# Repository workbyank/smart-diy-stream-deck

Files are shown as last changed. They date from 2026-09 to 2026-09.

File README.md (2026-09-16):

# Smart DIY Stream Deck

A custom USB HID macro controller with 9 programmable keys, OLED system monitoring, rotary volume control, and a 3D-printed enclosure.

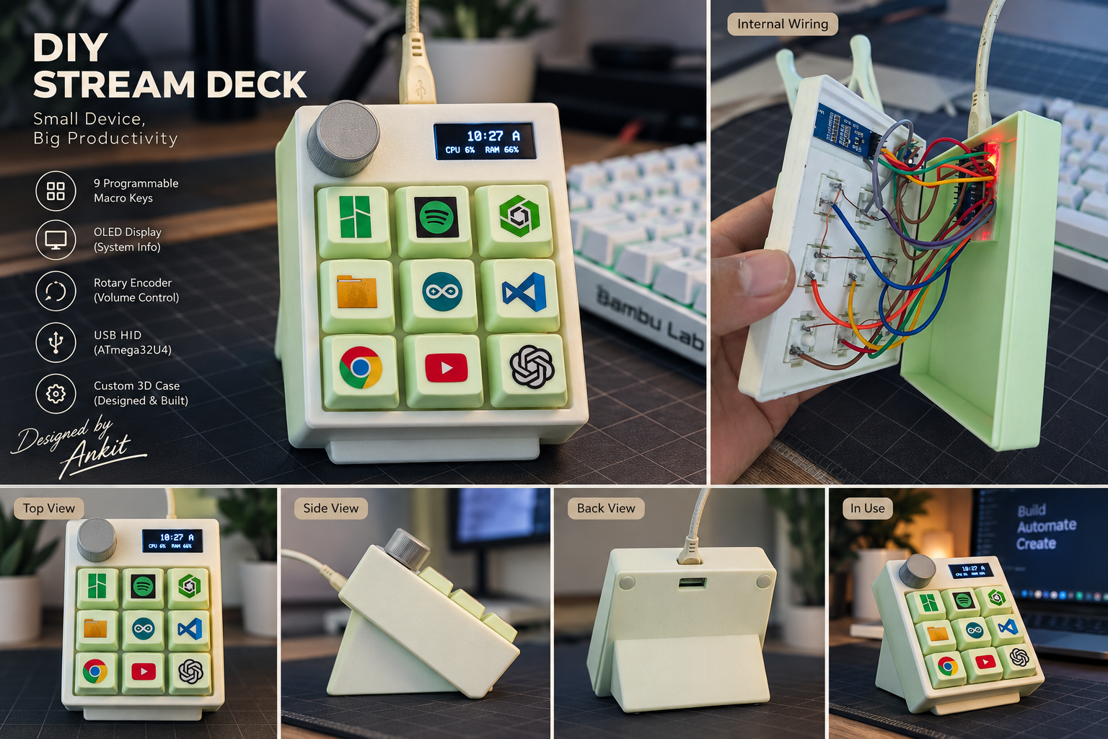
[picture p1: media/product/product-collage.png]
Smart DIY Stream Deck


`Arduino` `ATmega32U4` `USB HID` `AutoHotkey` `Onshape` `3D Printing`

---

## Overview

Smart DIY Stream Deck is a **9-key USB macro pad** built around an ATmega32U4 Pro Micro. It launches applications and websites, controls Windows system volume through a rotary encoder, and uses its OLED screen to show live feedback — including, once idle, the PC's current time, CPU load, and RAM usage.

The project spans firmware, desktop automation, serial communication, and mechanical design:

- Embedded systems (Arduino/AVR)
- USB HID (keyboard + consumer control)
- OLED / I2C display programming
- Rotary encoder input handling
- Desktop automation (AutoHotkey)
- Serial communication (USB-CDC)
- 3D CAD and 3D printing

This repository documents the project as it was actually built — implemented features and known limitations are called out explicitly throughout.

---

## Key Features

- 9 programmable macro keys
- Direct USB HID keyboard shortcuts (no clipboard tricks, no Win+R)
- Per-key application/website launching via a Windows-side launcher
- OLED status interface with a per-app icon and drop-in animation
- Idle screen showing PC time, CPU usage, and RAM usage
- Rotary encoder volume control (clockwise/counter-clockwise)
- Encoder push-button mute/unmute
- Custom 3D-printed enclosure
- AutoHotkey-based desktop automation (application launching + PC telemetry)
- Native USB on the ATmega32U4 (HID and Serial share one USB connection)

---

## Demo / Preview

The collage above shows the assembled macro pad from multiple angles (top, side, back, in active use) and the internal wiring, all from a single project photo set.

---

## Hardware

| Component | Qty | Purpose |
|---|---|---|
| ATmega32U4 Pro Micro (5V / 16MHz) | 1 | Main controller, native USB HID |
| 0.91" 128×32 I2C OLED | 1 | Status / idle display |
| Mechanical push switches | 9 | Macro key inputs |
| Rotary encoder with push switch | 1 | Volume control + mute |
| USB cable | 1 | Power + USB HID/Serial |
| Custom 3D-printed enclosure | 1 | Housing |
| Connecting wires | as required | Wiring |

Full details: [`hardware/bill-of-materials.md`](hardware/bill-of-materials.md)

---

## Key Mapping

| Key | Application | Action |
|---|---|---|
| K1 | ChatGPT | Launch (website) |
| K2 | Bambu Studio | Launch (desktop app) |
| K3 | Spotify | Launch (`spotify:` URI) |
| K4 | YouTube | Launch (website) |
| K5 | Chrome | Launch (desktop app) |
| K6 | Claude | Launch (website) |
| K7 | Arduino IDE | Launch (desktop app) |
| K8 | File Explorer | Launch (`explorer.exe`) |
| K9 | Onshape | Launch (website) |

Key assignments are defined entirely in [`software/macropad_launcher.ahk`](software/macropad_launcher.ahk) — changing what a key does never requires touching or re-flashing the firmware.

---

## System Architecture

```
                    SMART DIY STREAM DECK
                            |
             +--------------+--------------+
             |                             |
        ATmega32U4                     Windows PC
             |                             |
      +------+-------+              +------+-------+
      |      |       |              |              |
    Keys   OLED   Encoder       AutoHotkey    AutoHotkey
      |      |       |          (launcher)   (PC stats)
      |      |       |              |              |
      |      |       +----------> Volume       CPU/RAM/Time
      |      |                             |
      +------+-----------------------------+
                     USB (HID + Serial/CDC)
```

Full write-up: [`documentation/architecture.md`](documentation/architecture.md)

The system is a **two-layer architecture**:

- **Hardware/Firmware layer:** physical key press → ATmega32U4 → USB HID shortcut (`Ctrl+Alt+1`...`Ctrl+Alt+9`)
- **PC software layer:** USB HID shortcut → AutoHotkey → application/website launch

---

## Circuit Diagram

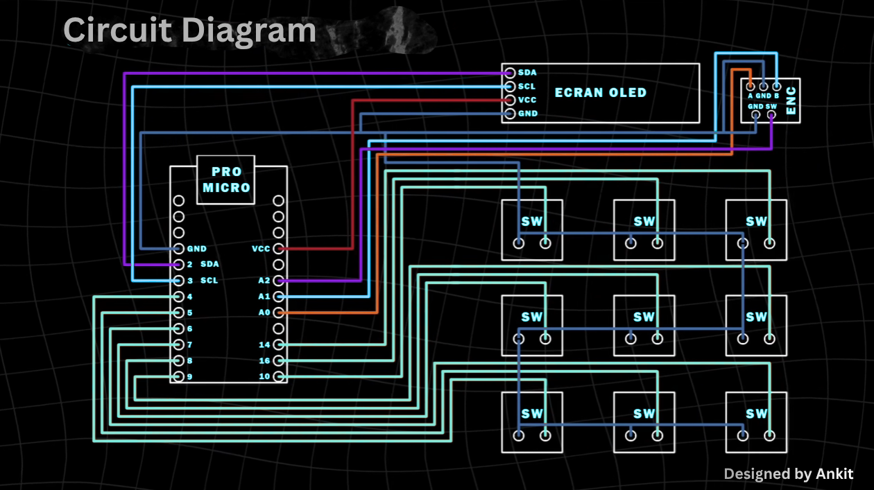
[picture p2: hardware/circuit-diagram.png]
Circuit Diagram


This is the project's wiring reference (not a PCB schematic). Full pin tables: [`hardware/pinout.md`](hardware/pinout.md)

---

## Software Architecture

Two independent AutoHotkey scripts run on the PC side. They were deliberately kept separate — an earlier combined script caused instability (see [Troubleshooting](documentation/troubleshooting.md)).

| Script | Responsibility |
|---|---|
| `software/macropad_launcher.ahk` | Listens for `Ctrl+Alt+1..9`, launches the matching application/website |
| `software/macropad_pc_stats.ahk` | Independently reads Windows time, CPU load, and RAM usage, and sends them to the Pro Micro over `COM7` at 9600 baud, roughly every 2 seconds |

**Note on the PC-stats sender:** it's implemented in AutoHotkey (not PowerShell) — see [`software/README.md`](software/README.md) for details.

Both scripts can be placed in the Windows Startup folder to run automatically; the Arduino IDE does **not** need to stay open after the firmware is flashed. See [`documentation/setup.md`](documentation/setup.md).

---

## OLED Behavior

| State | What's shown |
|---|---|
| Startup | "Macropad Ready" |
| Key press | Application icon (drop-in animation) + label |
| Encoder rotation | Volume level bar |
| Encoder press | MUTE / UNMUTE |
| ~30s idle, fresh PC data available | Time, CPU %, RAM % |
| ~30s idle, no fresh PC data | Display turns off |

Idle-screen data format received over serial: `HH:MM|CPU|RAM` (e.g. `10:27|6|66`).

This is a **PC-assisted** monitoring screen — the Pro Micro has no clock or performance sensors of its own; all of the idle-screen data originates from the PC-stats AutoHotkey script over serial. If that script stops running (or the data goes stale), the OLED falls back to turning off rather than showing frozen information.

---

## 3D Model

[`3d-model/Macropad.3mf`](3d-model/Macropad.3mf) — the 3D-printed enclosure model, importable into any 3MF-compatible CAD/slicer software (e.g. Bambu Studio, PrusaSlicer, most modern slicers).

The file's own metadata identifies Bambu Studio as the application it was exported/sliced from. Onshape was used elsewhere in the project's CAD workflow. Exact dimensions and print settings are not documented here beyond what the file itself contains — open it in your slicer to inspect them directly.

---

## Setup

Full step-by-step instructions: [`documentation/setup.md`](documentation/setup.md)

Quick summary:
1. Wire the hardware per [`hardware/pinout.md`](hardware/pinout.md)
2. Flash [`firmware/smart_stream_deck.ino`](firmware/smart_stream_deck.ino) via Arduino IDE
3. Install AutoHotkey v2
4. Run `software/macropad_launcher.ahk` and `software/macropad_pc_stats.ahk`
5. (Optional) add both scripts to Windows Startup for automatic launch

---

## Troubleshooting

Real issues hit during development, and how they were resolved: [`documentation/troubleshooting.md`](documentation/troubleshooting.md)

---

## Development Journey

Chronological build log: [`documentation/development-log.md`](documentation/development-log.md)

---

## Testing

| Test | Expected Result | Status |
|---|---|---|
| Power-on | OLED shows "Macropad Ready" | Verified during development |
| 9 macro keys | Each key opens its mapped app/website | Verified during development |
| Volume — clockwise | Windows volume increases | Verified during development |
| Volume — counter-clockwise | Windows volume decreases | Verified during development |
| Encoder mute | Mute/unmute toggles, OLED shows status | Verified during development |
| OLED startup | "Macropad Ready" message on boot | Verified during development |
| OLED application feedback | Correct icon + label per key | Verified during development |
| PC time transfer | Correct time shown on idle screen | Verified during development |
| CPU/RAM transfer | Correct percentages shown on idle screen | Verified during development |
| 30-second idle screen | Switches to time/CPU/RAM after ~30s | Verified during development |
| USB reconnection | Device resumes normally after unplug/replug | Not explicitly re-tested — not expected to require special handling |
| Windows startup | Both scripts auto-launch from Startup folder | Not explicitly re-tested end-to-end after setup |

Status reflects what was actually exercised during this project's build/debug process — it is not a claim of exhaustive or formal QA coverage.

---

## Future Improvements

Not implemented — listed here as possible future scope only:

- Custom PCB
- RGB backlighting
- Multiple key-mapping profiles
- User-configurable macros (without editing the `.ahk` source)
- Wireless version
- Refined enclosure design
- Web-based configuration UI
- Per-application profiles
- Additional sensors
- More advanced OLED UI

---

## Credits

**Designed & Built by Ankit**

Special thanks:
- **Aditya Kumar** — Videography & Editing
- **Rishi** — Technical Support & Assistance

---

## License

MIT License — see [`LICENSE`](LICENSE).

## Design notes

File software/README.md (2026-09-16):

# Software

Two independent AutoHotkey (v2) scripts run on the PC side. They are kept fully separate on purpose — see [`documentation/troubleshooting.md`](../documentation/troubleshooting.md), Issue 2.

## `macropad_launcher.ahk`

Listens for `Ctrl+Alt+1` through `Ctrl+Alt+9` (sent by the firmware) and launches the mapped application or website. Key → app/website assignments live in the `Targets` map near the top of the file — no firmware changes are needed to reassign a key.

Includes:
- Direct URL launching for web-based targets (ChatGPT, YouTube, Claude, Onshape, Spotify's `spotify:` URI)
- Automatic executable detection for a few desktop apps (Chrome, Arduino IDE)
- A manual path override (`ManualPaths`) for apps whose install location isn't predictable — currently used for Bambu Studio

## `macropad_pc_stats.ahk`

A separate, independent script with no hotkeys. On a timer, it:
1. Queries Windows for CPU load and RAM usage via WMI, and reads the current time
2. Opens the Pro Micro's COM port (`COM7` by default — **machine-specific**, change `StatsPort` to match your system)
3. Writes one line: `HH:MM|CPU|RAM\n` at 9600 baud, roughly every 2 seconds

> **Note:** despite being described conceptually as a "PC statistics sender," this is implemented in **AutoHotkey**, not PowerShell — this matches what was actually built and tested for this project.

## `Macropad_PC_Stats.lnk`

A Windows shortcut used to launch `macropad_pc_stats.ahk`, intended to be placed in the Windows Startup folder so the PC-stats sender starts automatically on login.

## Requirements

- [AutoHotkey v2](https://www.autohotkey.com/)
- Windows (both scripts use Windows-specific APIs — WMI for stats, `Run()` for launching)

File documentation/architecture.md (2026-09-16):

# System Architecture — Smart DIY Stream Deck

```
                    SMART DIY STREAM DECK
                            |
             +--------------+--------------+
             |                             |
        ATmega32U4                     Windows PC
             |                             |
      +------+-------+              +------+-------+
      |      |       |              |              |
    Keys   OLED   Encoder       AutoHotkey    AutoHotkey
      |      |       |          (launcher)   (PC stats)
      |      |       |              |              |
      |      |       +----------> Volume       CPU/RAM/Time
      |      |                             |
      +------+-----------------------------+
                     USB (HID + Serial/CDC)
```

## Layers

### 1. Hardware layer (ATmega32U4 Pro Micro)

- **Keys** — 9 push buttons, read with `INPUT_PULLUP`, debounced in firmware. A key press triggers an OLED icon animation and sends a `Ctrl+Alt+N` USB HID shortcut.
- **OLED** — 128×32 I2C display. Shows startup message, per-key icon/label, volume level, mute status, and (when idle) PC time/CPU/RAM.
- **Rotary encoder** — quadrature-decoded in firmware using a transition table; drives `Consumer.write(MEDIA_VOLUME_UP/DOWN)` for volume, and toggles mute on push.

### 2. PC software layer (Windows, AutoHotkey)

- **`macropad_launcher.ahk`** — binds `Ctrl+Alt+1..9` to `Run()` calls that open the mapped application or website. Handles manual path overrides and automatic executable detection for a few desktop apps.
- **`macropad_pc_stats.ahk`** — a fully separate, independent script. On a timer, it queries Windows for the current time, CPU load, and RAM usage via WMI, then writes a single line (`HH:MM|CPU|RAM`) to the Pro Micro's COM port at 9600 baud.

These two scripts do not share code or state — this was a deliberate design decision after an earlier combined script caused instability (see [`troubleshooting.md`](troubleshooting.md)).

### 3. USB link

The ATmega32U4's native USB exposes two interfaces over one physical cable:

- **HID** — keyboard shortcuts + consumer control (volume/mute), via the HID-Project library.
- **Serial/CDC** — a virtual COM port used only for the one-way PC → firmware idle-stats feed.

## Data flow: pressing a macro key

```
Physical key press
   → ATmega32U4 detects the press (debounced)
   → OLED animates the app icon + label
   → Firmware sends Ctrl+Alt+N over USB HID
   → macropad_launcher.ahk receives the hotkey
   → Application/website launches on Windows
```

## Data flow: idle screen

```
macropad_pc_stats.ahk (every ~2s)
   → Queries Windows time, CPU load (WMI), RAM usage (WMI)
   → Writes "HH:MM|CPU|RAM\n" to COM7 at 9600 baud
   → Firmware reads the line over Serial (non-blocking)
   → Firmware parses time/CPU/RAM into internal variables
   → After ~30s of key/encoder inactivity, OLED shows this data
   → If no fresh data arrives within the timeout window, OLED turns off instead
```

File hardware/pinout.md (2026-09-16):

# Pinout — Smart DIY Stream Deck

Controller: **ATmega32U4 Pro Micro (5V / 16MHz)**

Exact silkscreen labels can vary slightly between Pro Micro board variants/clones — match by pin function (e.g. "A0", "A1", "SDA") rather than by physical position if your board differs.

---

## OLED (I2C)

| OLED Pin | Pro Micro Pin | Notes |
|---|---|---|
| SDA | 2 (SDA) | I2C data |
| SCL | 3 (SCL) | I2C clock |
| VCC | VCC | 5V |
| GND | GND | Ground |

- Display: 0.91", 128×32, I2C
- I2C address used in firmware: `0x3C`
- Firmware runs I2C at 400kHz (`Wire.setClock(400000)`) for faster redraws

---

## Rotary Encoder

| Encoder Pin | Pro Micro Pin | Notes |
|---|---|---|
| A / CLK | A1 | Quadrature signal A |
| B / DT | A0 | Quadrature signal B |
| SW | A2 | Push-button (mute/unmute) |
| VCC | VCC | 5V |
| GND | GND | Ground |

All three encoder pins (`A1`, `A0`, `A2`) are configured `INPUT_PULLUP` in firmware.

---

## Macro Keys (9x)

All 9 keys are configured `INPUT_PULLUP` — each switch connects its pin to GND when pressed (active LOW).

| Key | Pro Micro Pin |
|---|---|
| K1 | 4 |
| K2 | 14 |
| K3 | 16 |
| K4 | 5 |
| K5 | 6 |
| K6 | 7 |
| K7 | 8 |
| K8 | 9 |
| K9 | 10 |

Firmware array: `KEY_PINS[9] = {4, 14, 16, 5, 6, 7, 8, 9, 10}`

---

## USB

The ATmega32U4 provides native USB, exposing two logical interfaces over the **same USB cable**:

| Interface | Purpose |
|---|---|
| USB HID (Keyboard + Consumer Control) | Sends `Ctrl+Alt+1..9` macro shortcuts and media/volume commands (via HID-Project) |
| USB Serial / CDC | Carries PC time/CPU/RAM data from the PC-stats script to the firmware (9600 baud) |

These are separate logical channels handled by the same USB stack — they don't interfere with each other.

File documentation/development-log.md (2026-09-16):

# Development Log

A chronological look at how the project came together. No specific dates are given here beyond what's independently confirmed by project files.

## Phase 1 — Concept

The goal was a compact, Stream-Deck-style productivity controller: a small physical device to launch frequently-used apps and websites with one press, plus basic system controls, without needing a commercial product.

## Phase 2 — Hardware Prototype

Core hardware assembled: an ATmega32U4 Pro Micro, a 0.91" 128×32 I2C OLED, 9 mechanical push switches, and a rotary encoder with a push switch, wired per [`hardware/pinout.md`](../hardware/pinout.md).

## Phase 3 — Firmware

Firmware built up incrementally:
- Key detection with debouncing
- USB HID shortcut output (`Ctrl+Alt+1..9`) via HID-Project
- Rotary encoder quadrature decoding for volume, and push-to-mute
- OLED UI: startup message, volume bar, mute status
- Per-key icon and drop-in animation on the OLED
- Idle-screen display (time/CPU/RAM) fed by serial data from the PC

## Phase 4 — Desktop Automation

`macropad_launcher.ahk` written to catch the `Ctrl+Alt+1..9` shortcuts and launch the mapped application or website, including automatic executable detection for a few desktop apps and a manual path override for Bambu Studio.

## Phase 5 — PC Monitoring

Serial communication added between the PC and firmware: a script queries Windows for time, CPU load, and RAM usage via WMI and forwards it to the Pro Micro, which displays it during idle periods.

## Phase 6 — Debugging

Real issues surfaced and were resolved along the way — wrong board profile tripping up HID-Project, instability from combining the launcher and PC-stats logic into one script, COM-port handling, getting the scripts to run hidden in the background, and defining clear stale-data behavior for the OLED. Full details: [`troubleshooting.md`](troubleshooting.md).

## Phase 7 — Mechanical Design

A custom 3D-printed enclosure was designed and printed to house the electronics, with Onshape used in the CAD workflow and Bambu Studio used for slicing (confirmed by the exported `3mf` file's own metadata).

## Phase 8 — Final Prototype

All pieces integrated into a single working unit: 9 macro keys, encoder-based volume/mute, OLED feedback and idle monitoring, and PC-side automation — assembled into the enclosure and in daily use.

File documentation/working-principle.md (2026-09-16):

# Working Principle — Smart DIY Stream Deck

Step-by-step behavior from power-on:

1. Device powers on through USB.
2. The ATmega32U4 initializes — pins, USB HID (Keyboard + Consumer), and USB Serial.
3. The OLED initializes over I2C and shows **"Macropad Ready"**.
4. The 9 key pins and 3 encoder pins are configured as `INPUT_PULLUP`.
5. USB HID becomes active — the PC recognizes the device as a keyboard/consumer-control HID device, plus a serial (CDC) port.
6. **User presses a macro key.**
7. Firmware detects the press, animates the corresponding icon on the OLED, and sends `Ctrl+Alt+N` as a USB HID shortcut.
8. `macropad_launcher.ahk` (running on the PC) receives the shortcut.
9. The corresponding application or website launches.
10. **Turning the encoder** sends `MEDIA_VOLUME_UP` / `MEDIA_VOLUME_DOWN` consumer-control HID commands, adjusting Windows system volume; the OLED shows an internal volume-level bar.
11. **Pressing the encoder** toggles mute (`MEDIA_VOLUME_MUTE`) and updates the OLED accordingly.
12. Independently, `macropad_pc_stats.ahk` periodically collects the current time, CPU load, and RAM usage from Windows via WMI.
13. That data is sent to the Pro Micro over its COM port (9600 baud) as a single line: `HH:MM|CPU|RAM`.
14. Firmware reads this line over Serial (non-blocking) and parses the three fields.
15. After roughly 30 seconds without a key press or encoder movement, and if fresh PC data is available, the OLED switches to an idle screen showing time, CPU%, and RAM%, refreshed about once per second.
16. If PC data becomes stale (the PC-stats script isn't running, or the connection drops), the OLED turns off instead of displaying frozen, outdated information.

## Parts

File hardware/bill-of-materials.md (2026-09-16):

# Bill of Materials — Smart DIY Stream Deck

| Component | Quantity | Purpose |
|---|---|---|
| ATmega32U4 Pro Micro | 1 | Main controller / USB HID |
| 128×32 I2C OLED (0.91") | 1 | Display |
| Push buttons | 9 | Macro inputs |
| Rotary encoder (with push switch) | 1 | Volume control + mute |
| USB cable | 1 | Power and USB communication |
| Connecting wires | As required | Wiring |
| 3D-printed enclosure | 1 | Mechanical housing |

Prices are not listed — they vary significantly by supplier, region, and time of purchase.

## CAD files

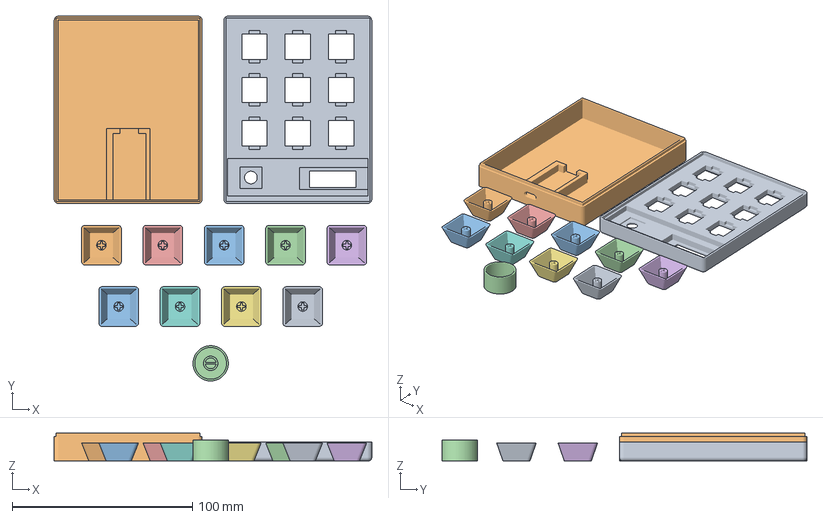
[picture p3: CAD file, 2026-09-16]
3d-model/Macropad.3mf
176.0 x 202.3 x 15.5 mm
Boitier
bottom
keycaps x 9
Bouton

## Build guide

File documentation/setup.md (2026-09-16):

# Setup Guide — Smart DIY Stream Deck

## 1. Hardware Wiring

Wire the OLED, rotary encoder, and 9 push buttons to the Pro Micro exactly as described in [`hardware/pinout.md`](../hardware/pinout.md) and shown in [`hardware/circuit-diagram.png`](../hardware/circuit-diagram.png).

## 2. Arduino IDE Setup

1. Install the [Arduino IDE](https://www.arduino.cc/en/software).
2. Install the required libraries via **Sketch → Include Library → Manage Libraries**:
   - `HID-Project`
   - `Adafruit GFX Library`
   - `Adafruit SSD1306`
3. **Board selection matters:** select a genuine USB-capable ATmega32U4 profile (e.g. **Arduino Leonardo** or **SparkFun Pro Micro**, matching your specific board). A non-USB board profile (like a classic Pro Mini configuration) will cause HID-Project to fail — see [`troubleshooting.md`](troubleshooting.md), Issue 1.

## 3. Flashing the Firmware

1. Open [`firmware/smart_stream_deck.ino`](../firmware/smart_stream_deck.ino) in the Arduino IDE.
2. Select the correct board and COM port.
3. Upload.
4. Once uploaded, **the Arduino IDE does not need to stay open** — the device runs independently once plugged into any USB port, powered or not connected to the IDE.

## 4. AutoHotkey Setup

1. Install [AutoHotkey v2](https://www.autohotkey.com/).
2. Run [`software/macropad_launcher.ahk`](../software/macropad_launcher.ahk) by double-clicking it. A tray icon confirms it's running.
3. Test a key press — the mapped application/website should open.
4. If an app doesn't open (e.g. it's installed somewhere non-standard), edit the `ManualPaths` map at the top of the script with the correct `.exe` path.

## 5. PC Stats Sender Setup

1. Run [`software/macropad_pc_stats.ahk`](../software/macropad_pc_stats.ahk) separately from the launcher.
2. **Find your Pro Micro's COM port** in Windows Device Manager → Ports (COM & LPT). The script currently targets `COM7` — this was the port used during development and **will likely be different on your PC**. Edit the `StatsPort` variable at the top of the script to match.
3. Once running, wait ~30 seconds without touching the macropad — the OLED should switch to the idle time/CPU/RAM screen.

## 6. Windows Startup (Optional)

To have both scripts run automatically on login, without needing to double-click them each time:

1. Press `Win+R`, type `shell:startup`, press Enter.
2. Create shortcuts to `macropad_launcher.ahk` and `macropad_pc_stats.ahk`, and place them in this folder.
3. The Pro Micro must remain connected via USB for either script to function.

The Arduino IDE does **not** need to be part of Windows Startup — only the two AutoHotkey scripts.

## 7. Testing

Once everything is wired and running:

- Press each of the 9 keys and confirm the correct app/website opens and the OLED shows the right icon.
- Rotate the encoder both directions and confirm system volume changes.
- Press the encoder and confirm mute/unmute toggles.
- Leave the macropad idle for ~30 seconds and confirm the OLED shows time/CPU/RAM (with the PC-stats script running).
- Close the PC-stats script and confirm the OLED falls back to turning off after the idle timeout, rather than showing frozen data.

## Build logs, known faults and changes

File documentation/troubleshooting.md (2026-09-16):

# Troubleshooting & Debugging History

Real issues encountered during development, kept here honestly rather than hidden.

## Issue 1 — HID-Project board error

**Symptom:** `HID Project can only be used with an USB MCU`

**Cause:** Wrong board profile selected in the Arduino IDE — a non-USB board configuration was selected instead of a USB-capable one.

**Resolution:** Select a genuine USB-capable ATmega32U4 board profile (e.g. Arduino Leonardo / SparkFun Pro Micro configuration), not a classic non-USB Pro Mini-style profile.

## Issue 2 — Combined launcher + PC-stats script instability

**Symptom:** Running application launching and serial PC-stats communication from within the same AutoHotkey script caused instability.

**Resolution:** Split the functionality into two fully independent scripts — `macropad_launcher.ahk` (hotkeys only) and `macropad_pc_stats.ahk` (serial telemetry only) — with no shared state between them.

## Issue 3 — COM port is machine-specific

**Symptom:** The PC-stats script is hardcoded to `COM7`.

**Explanation:** `COM7` was simply the port Windows assigned to the Pro Micro on the development machine. COM port numbers are assigned by Windows and **will very likely differ on another PC**. Check Device Manager → Ports (COM & LPT) and update the `StatsPort` value in `macropad_pc_stats.ahk` accordingly.

## Issue 4 — Stats/launcher window appearing on screen

**Symptom:** Running the scripts could show a visible window or flash a console.

**Resolution:** Run both AutoHotkey scripts via a Windows Startup shortcut so they launch hidden in the background — AutoHotkey scripts don't show a console window by default when run this way.

## Issue 5 — OLED going blank after inactivity

**Symptom:** After a period of inactivity, the OLED turns off.

**Cause:** This is intentional firmware behavior — the OLED only shows the idle time/CPU/RAM screen while **fresh** PC-stats data is being received. If no fresh data has arrived within the configured timeout, the firmware turns the display off rather than showing stale, frozen information.

## Issue 6 — Serial Monitor conflict

**Symptom:** The PC-stats script fails to open the COM port.

**Cause:** The Arduino IDE's Serial Monitor or Serial Plotter was left open, holding the same COM port.

**Resolution:** Close the Serial Monitor/Plotter before running `macropad_pc_stats.ahk` — only one program can hold a COM port open at a time.

## Issue 7 — Bambu Studio executable path

**Symptom:** Bambu Studio wouldn't launch via automatic detection.

**Cause:** Bambu Studio's install location isn't always predictable across machines.

**Resolution:** A manual path override (`ManualPaths` map in `macropad_launcher.ahk`) is used instead of relying solely on auto-detection. The path used during development — `D:\Bambu Studio\bambu-studio.exe` — is specific to that machine and will need to be changed for any other setup.

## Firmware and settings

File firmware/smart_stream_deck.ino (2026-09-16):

/************ GENERIC MACRO PAD : OLED + ENCODER + 9 KEYS ************/
/*
   V3 — bigger auto-sized label font, improved Spotify/ChatGPT icons,
   and an idle screen that shows the PC's time + CPU/RAM usage instead
   of just turning the OLED off, once it's been idle a while.

   The idle info comes from your PC over the SAME USB cable, using the
   Arduino's separate USB-Serial (CDC) interface — this runs alongside
   HID-Project's keyboard/media features without conflict, it's just a
   second "channel" on the same USB connection.

   Format expected over Serial (9600 baud), one line, ending in '\n':
       HH:MM|CPU|RAM
   e.g.  14:23|37|61
   Sent automatically every ~2s by the updated macropad_launcher.ahk.

   If no data has ever arrived (script not running / not detected the
   COM port yet), it falls back to the old behaviour: OLED turns off
   after 30s idle, same as before. If data stops arriving for a while,
   (script closed), it also falls back to turning off, instead of
   showing a frozen, stale clock forever.

   Everything else (Ctrl+Alt+1..9 direct launch, encoder volume, mute,
   debouncing) is unchanged from the previous version.

   ------------------------------------------------------------
   Designed and Developed by Ankit
   ------------------------------------------------------------
*/

#include <HID-Project.h>              // HID Keyboard + Consumer (volume/media)
#include <Wire.h>
#include <Adafruit_GFX.h>
#include <Adafruit_SSD1306.h>
#include <string.h>
#include <stdlib.h>
#include <math.h>

/* -------------------- OLED -------------------- */
#define SCREEN_WIDTH 128
#define SCREEN_HEIGHT 32
Adafruit_SSD1306 display(SCREEN_WIDTH, SCREEN_HEIGHT, &Wire, -1);
const uint8_t OLED_ADDR = 0x3C; // Adresse I2C (souvent 0x3C ou 0x3D)

/* -------------------- PINS -------------------- */
const uint8_t ENC_A  = A1;
const uint8_t ENC_B  = A0;
const uint8_t ENC_SW = A2;

const uint8_t KEY_PINS[9] = { 4, 14, 16, 5, 6, 7, 8, 9, 10 };

/* ---------------- Identifiants touches ---------------- */
enum KeyIds { K1, K2, K3, K4, K5, K6, K7, K8, K9 };
bool lastKeyState[9];

const char* KEY_LABELS[9] = {
  "ChatGPT",
  "Bambu Studio",
  "Spotify",
  "YouTube",
  "Chrome",
  "Claude",
  "Arduino",
  "File Explorer",
  "Onshape"
};

/* ---------- Encodeur ---------- */
int8_t transTable[16] = {0,-1,+1,0, +1,0,0,-1, -1,0,0,+1, 0,+1,-1,0};
uint8_t lastAB=0; int8_t accum=0;
const uint8_t STEPS_PER_DETENT=4;
unsigned long lastStepMs=0, lastClickMs=0;
const unsigned long STEP_COOLDOWN_MS=2, CLICK_DEBOUNCE_MS=200;

/* ---------- OLED veille ---------- */
unsigned long lastActionTime=0;
const unsigned long SLEEP_DELAY=30000; // 30 s d'inactivité avant veille/idle screen
bool isSleeping=false;

/* ---------- Volume simulé ---------- */
int currentVol=50; bool muted=false;

/* ---------- Throttle du redraw OLED (fix encodeur) ---------- */
unsigned long lastDisplayRefresh = 0;
const unsigned long DISPLAY_REFRESH_MS = 60;
bool volPending = false;

/* ---------- Animation d'icône (non-bloquante) ---------- */
const int ICON_W = 16;
const int ICON_H = 16;
const int ICON_X = 3;
const int ICON_Y_REST = (SCREEN_HEIGHT - ICON_H) / 2;   // 8
const int ICON_Y_START = -ICON_H - 2;
const int TEXT_X = ICON_X + ICON_W + 6;

bool animActive = false;
uint8_t animIconId = 0;
int animY = ICON_Y_START;
unsigned long animLastFrame = 0;
const unsigned long ANIM_FRAME_MS = 16;

/* ---------- Infos PC reçues en Serial (pour l'écran de veille) ---------- */
char serialBuffer[40];
uint8_t serialBufIdx = 0;
char idleTimeStr[8] = "";   // "HH:MM"
int idleCpu = -1, idleRam = -1;
bool hasIdleData = false;
unsigned long lastIdleDataMs = 0;
unsigned long lastIdleRefresh = 0;
const unsigned long IDLE_REFRESH_MS = 1000;        // rafraîchit l'écran d'idle 1x/s
const unsigned long IDLE_DATA_TIMEOUT_MS = 6000;   // si pas de data depuis 6s -> considère le PC-script arrêté

/* ---------------- PROTOTYPES ---------------- */
void showMessage(const char* msg);
void showVolume();
void maybeShowVolume();
void wakeUp();
void fireMacro(uint8_t id);
void sendAppLaunch(uint8_t id);
void startAppAnimation(uint8_t id);
void updateAppAnimation();
void renderAppFrame(uint8_t id, int iconY);
void drawAppIcon(uint8_t id, int x, int y);
void drawArc(int cx, int cy, int r, float startDeg, float endDeg);
uint8_t chooseLabelSize(const char* label);
int chooseLabelY(uint8_t size);
void readSerialIdleData();
void parseIdleLine(char* line);
void showIdleScreen();

/* ==================== SETUP ==================== */
void setup() {
  for (int i=0;i<9;i++){ pinMode(KEY_PINS[i], INPUT_PULLUP); lastKeyState[i]=digitalRead(KEY_PINS[i]); }
  pinMode(ENC_A,INPUT_PULLUP); pinMode(ENC_B,INPUT_PULLUP); pinMode(ENC_SW,INPUT_PULLUP);
  lastAB = (digitalRead(ENC_A)<<1) | digitalRead(ENC_B);

  Keyboard.begin();
  Consumer.begin();
  Serial.begin(9600); // canal séparé pour recevoir l'heure / CPU / RAM du PC

  Wire.begin();
  Wire.setClock(400000);
  if(!display.begin(SSD1306_SWITCHCAPVCC, OLED_ADDR)){ for(;;); }
  display.clearDisplay(); display.setTextSize(1); display.setTextColor(SSD1306_WHITE);
  display.setCursor(0,0); display.println(F("Macropad Ready")); display.display();

  lastActionTime = millis();
  showVolume();
}

/* ==================== LOOP ==================== */
void loop() {
  readSerialIdleData();

  // --- 9 touches ---
  for (uint8_t i=0;i<9;i++){
    bool pressed = (digitalRead(KEY_PINS[i])==LOW);
    if (pressed && !lastKeyState[i]) { wakeUp(); fireMacro(i); }
    lastKeyState[i]=pressed;
  }

  updateAppAnimation();

  // --- Rotation encodeur -> Volume ---
  uint8_t nowAB = (digitalRead(ENC_A)<<1)|digitalRead(ENC_B);
  int8_t dir = transTable[(lastAB<<2)|nowAB];
  if (dir!=0){
    accum += dir; lastAB = nowAB;
    if (millis()-lastStepMs > STEP_COOLDOWN_MS){
      if (accum >= STEPS_PER_DETENT){
        wakeUp(); currentVol=min(100,currentVol+2); Consumer.write(MEDIA_VOLUME_UP);
        if (!animActive) maybeShowVolume();
        accum -= STEPS_PER_DETENT; lastStepMs=millis();
      } else if (accum <= -STEPS_PER_DETENT){
        wakeUp(); currentVol=max(0,currentVol-2); Consumer.write(MEDIA_VOLUME_DOWN);
        if (!animActive) maybeShowVolume();
        accum += STEPS_PER_DETENT; lastStepMs=millis();
      }
    }
  } else lastAB=nowAB;

  if (!animActive && volPending && (millis()-lastStepMs > DISPLAY_REFRESH_MS)){
    showVolume(); lastDisplayRefresh=millis(); volPending=false;
  }

  // --- Clic bouton encodeur -> Mute ---
  if (digitalRead(ENC_SW)==LOW && (millis()-lastClickMs>CLICK_DEBOUNCE_MS)){
    lastClickMs=millis(); wakeUp(); muted=!muted; Consumer.write(MEDIA_VOLUME_MUTE);
    animActive=false;
    showMessage(muted?"MUTE":"UNMUTE"); showVolume();
  }

  // --- Veille / écran d'idle ---
  if (!isSleeping && !animActive && (millis()-lastActionTime>SLEEP_DELAY)){
    bool dataFresh = hasIdleData && (millis()-lastIdleDataMs < IDLE_DATA_TIMEOUT_MS);
    if (dataFresh){
      if (millis()-lastIdleRefresh >= IDLE_REFRESH_MS){
        showIdleScreen();
        lastIdleRefresh = millis();
      }
    } else {
      display.ssd1306_command(SSD1306_DISPLAYOFF);
      isSleeping=true;
    }
  }
}

/* ==================== FONCTIONS ==================== */
void fireMacro(uint8_t id){
  startAppAnimation(id);
  sendAppLaunch(id);
}

void sendAppLaunch(uint8_t id){
  KeyboardKeycode digitKey = (KeyboardKeycode)(KEY_1 + id);
  Keyboard.press(KEY_LEFT_CTRL);
  Keyboard.press(KEY_LEFT_ALT);
  Keyboard.press(digitKey);
  delay(30);
  Keyboard.releaseAll();
}

/* -------- Lecture non-bloquante du Serial (heure/CPU/RAM du PC) -------- */
void readSerialIdleData(){
  while (Serial.available()){
    char c = Serial.read();
    if (c == '\n'){
      serialBuffer[serialBufIdx] = '\0';
      parseIdleLine(serialBuffer);
      serialBufIdx = 0;
    } else if (c != '\r'){
      if (serialBufIdx < sizeof(serialBuffer)-1){
        serialBuffer[serialBufIdx++] = c;
      } else {
        serialBufIdx = 0; // ligne trop longue / corrompue -> on l'ignore
      }
    }
  }
}

// Format attendu : "HH:MM|CPU|RAM"  (ex: "14:23|37|61")
void parseIdleLine(char* line){
  char* p1 = strchr(line, '|');
  if (!p1) return;
  *p1 = '\0';
  char* p2 = strchr(p1+1, '|');
  if (!p2) return;
  *p2 = '\0';

  strncpy(idleTimeStr, line, sizeof(idleTimeStr)-1);
  idleTimeStr[sizeof(idleTimeStr)-1] = '\0';
  idleCpu = atoi(p1+1);
  idleRam = atoi(p2+1);
  hasIdleData = true;
  lastIdleDataMs = millis();
}

void showIdleScreen(){
  display.ssd1306_command(SSD1306_DISPLAYON);
  display.clearDisplay();
  display.setTextColor(SSD1306_WHITE);

  display.setTextSize(2);
  display.setCursor(28, 0);
  display.print(idleTimeStr);

  display.setTextSize(1);
  display.setCursor(4, 22);
  display.print(F("CPU "));
  display.print(idleCpu);
  display.print(F("%   RAM "));
  display.print(idleRam);
  display.print(F("%"));

  display.display();
  // Ne touche PAS lastActionTime/isSleeping ici : c'est un affichage
  // "en arrière-plan" pendant l'idle, pas une action utilisateur.
}

/* -------- Animation : l'icône tombe du haut et se pose -------- */
void startAppAnimation(uint8_t id){
  animActive = true;
  animIconId = id;
  animY = ICON_Y_START;
  animLastFrame = millis();
  renderAppFrame(id, animY);
}

void updateAppAnimation(){
  if (!animActive) return;
  if (millis() - animLastFrame < ANIM_FRAME_MS) return;
  animLastFrame = millis();

  int remaining = ICON_Y_REST - animY;
  if (abs(remaining) <= 1) {
    animY = ICON_Y_REST;
    animActive = false;
  } else {
    int step = remaining / 3;
    if (step == 0) step = (remaining > 0) ? 1 : -1;
    animY += step;
  }
  renderAppFrame(animIconId, animY);
}

// Choisit une police plus grande (taille 2) quand le nom tient dans la
// largeur restante, sinon retombe sur la taille 1 pour ne pas déborder.
uint8_t chooseLabelSize(const char* label){
  return (strlen(label) <= 8) ? 2 : 1;
}

int chooseLabelY(uint8_t size){
  return (size == 2) ? (SCREEN_HEIGHT - 16) / 2 : (SCREEN_HEIGHT - 8) / 2 + 1;
}

void renderAppFrame(uint8_t id, int iconY){
  display.ssd1306_command(SSD1306_DISPLAYON);
  display.clearDisplay();

  const char* label = KEY_LABELS[id];
  uint8_t sz = chooseLabelSize(label);
  display.setTextSize(sz);
  display.setTextColor(SSD1306_WHITE);
  display.setCursor(TEXT_X, chooseLabelY(sz));
  display.println(label);

  drawAppIcon(id, ICON_X, iconY);
  display.display();
  lastActionTime = millis();
  isSleeping = false;
}

// Petit utilitaire pour dessiner un arc de cercle (Adafruit_GFX n'en a pas
// nativement) — utilisé pour l'icône Spotify.
void drawArc(int cx, int cy, int r, float startDeg, float endDeg){
  const int STEPS = 8;
  float startRad = startDeg * PI / 180.0;
  float endRad   = endDeg   * PI / 180.0;
  int px = cx + (int)(r * cos(startRad));
  int py = cy + (int)(r * sin(startRad));
  for (int i = 1; i <= STEPS; i++){
    float t = startRad + (endRad - startRad) * i / STEPS;
    int nx = cx + (int)(r * cos(t));
    int ny = cy + (int)(r * sin(t));
    display.drawLine(px, py, nx, ny, SSD1306_WHITE);
    px = nx; py = ny;
  }
}

/* -------- Icônes génériques 16x16 dessinées avec Adafruit_GFX -------- */
void drawAppIcon(uint8_t id, int x, int y){
  switch (id) {

    case K1: { // ChatGPT -> bulle de discussion + étincelle "IA"
      display.drawRoundRect(x, y, 14, 10, 3, SSD1306_WHITE);
      display.drawLine(x+3, y+9, x+1, y+14, SSD1306_WHITE);
      display.drawLine(x+4, y+9, x+3, y+13, SSD1306_WHITE);
      int scx = x+7, scy = y+5;
      display.drawLine(scx-3, scy,   scx+3, scy,   SSD1306_WHITE);
      display.drawLine(scx,   scy-2, scx,   scy+2, SSD1306_WHITE);
      display.drawLine(scx-2, scy-2, scx+2, scy+2, SSD1306_WHITE);
      display.drawLine(scx-2, scy+2, scx+2, scy-2, SSD1306_WHITE);
      break;
    }

    case K2: { // Bambu Studio -> cube filaire (impression 3D)
      display.drawLine(x+5, y+0,  x+11, y+3,  SSD1306_WHITE);
      display.drawLine(x+11,y+3,  x+5,  y+6,  SSD1306_WHITE);
      display.drawLine(x+5, y+6,  x+0,  y+3,  SSD1306_WHITE);
      display.drawLine(x+0, y+3,  x+5,  y+0,  SSD1306_WHITE);
      display.drawLine(x+5, y+6,  x+5,  y+13, SSD1306_WHITE);
      display.drawLine(x+0, y+3,  x+0,  y+10, SSD1306_WHITE);
      display.drawLine(x+11,y+3,  x+11, y+10, SSD1306_WHITE);
      display.drawLine(x+5, y+13, x+11, y+10, SSD1306_WHITE);
      display.drawLine(x+5, y+13, x+0,  y+10, SSD1306_WHITE);
      break;
    }

    case K3: { // Spotify -> cercle + 3 ondes sonores (arcs)
      display.drawCircle(x+8, y+8, 8, SSD1306_WHITE);
      display.fillCircle(x+4, y+11, 1, SSD1306_WHITE);
      drawArc(x+4, y+11, 4, -70, 10);
      drawArc(x+4, y+11, 6, -70, 10);
      drawArc(x+4, y+11, 8, -70, 10);
      break;
    }

    case K4: { // YouTube -> rectangle arrondi + triangle play
      display.drawRoundRect(x, y+2, 16, 11, 3, SSD1306_WHITE);
      display.fillTriangle(x+5, y+4, x+5, y+11, x+12, y+7, SSD1306_WHITE);
      break;
    }

    case K5: { // Chrome -> cercle type "globe/navigateur"
      display.drawCircle(x+7, y+7, 7, SSD1306_WHITE);
      display.drawFastHLine(x+0, y+7, 15, SSD1306_WHITE);
      display.fillCircle(x+7, y+7, 2, SSD1306_WHITE);
      break;
    }

    case K6: { // Claude -> star/sunburst (generic "AI assistant" icon)
      int scx = x+7, scy = y+7;
      display.drawLine(scx, scy-7, scx, scy+7, SSD1306_WHITE); // vertical
      display.drawLine(scx-7, scy, scx+7, scy, SSD1306_WHITE); // horizontal
      display.drawLine(scx-5, scy-5, scx+5, scy+5, SSD1306_WHITE); // diagonal
      display.drawLine(scx-5, scy+5, scx+5, scy-5, SSD1306_WHITE); // diagonal
      display.fillCircle(scx, scy, 2, SSD1306_WHITE); // centre
      break;
    }

    case K7: { // Arduino IDE -> puce électronique
      display.drawRect(x+3, y+3, 10, 10, SSD1306_WHITE);
      display.drawFastVLine(x+5,  y+0, 3, SSD1306_WHITE);
      display.drawFastVLine(x+8,  y+0, 3, SSD1306_WHITE);
      display.drawFastVLine(x+11, y+0, 3, SSD1306_WHITE);
      display.drawFastVLine(x+5,  y+13, 3, SSD1306_WHITE);
      display.drawFastVLine(x+8,  y+13, 3, SSD1306_WHITE);
      display.drawFastVLine(x+11, y+13, 3, SSD1306_WHITE);
      break;
    }

    case K8: { // File Explorer -> dossier
      display.drawRect(x+1, y+5, 14, 9, SSD1306_WHITE);
      display.drawRect(x+1, y+3, 6, 3, SSD1306_WHITE);
      break;
    }

    case K9: { // Onshape -> repère d'axes 3D (icône CAO)
      int cx = x+8, cy = y+14;
      display.drawLine(cx, cy, cx,   cy-13, SSD1306_WHITE);
      display.drawLine(cx, cy, cx+6, cy-3,  SSD1306_WHITE);
      display.drawLine(cx, cy, cx-6, cy-3,  SSD1306_WHITE);
      display.drawLine(cx, cy-13, cx-2, cy-11, SSD1306_WHITE);
      display.drawLine(cx, cy-13, cx+2, cy-11, SSD1306_WHITE);
      break;
    }
  }
}

void showMessage(const char* msg){
  display.ssd1306_command(SSD1306_DISPLAYON);
  display.clearDisplay(); display.setTextSize(1); display.setTextColor(SSD1306_WHITE);
  display.setCursor(0,8); display.println(msg); display.display();
  lastActionTime=millis(); isSleeping=false;
}

void maybeShowVolume(){
  volPending = true;
  if (millis()-lastDisplayRefresh >= DISPLAY_REFRESH_MS){
    showVolume();
    lastDisplayRefresh = millis();
    volPending = false;
  }
}

void showVolume(){
  display.ssd1306_command(SSD1306_DISPLAYON);
  display.clearDisplay(); display.setTextSize(1); display.setTextColor(SSD1306_WHITE); display.setCursor(0,0);
  if (muted) display.println(F("MUTE"));
  else { display.print(F("Volume: ")); display.print(currentVol); display.println('%'); }
  int barW = map(currentVol, 0, 100, 0, SCREEN_WIDTH-10);
  display.drawRect(5,16,SCREEN_WIDTH-10,10,SSD1306_WHITE);
  if (!muted && barW>0) display.fillRect(5,16,barW,10,SSD1306_WHITE);
  display.display(); lastActionTime=millis(); isSleeping=false;
}

void wakeUp(){ if(isSleeping){ display.ssd1306_command(SSD1306_DISPLAYON); isSleeping=false; } lastActionTime=millis(); }
